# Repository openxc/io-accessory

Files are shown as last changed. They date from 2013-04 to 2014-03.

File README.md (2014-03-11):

OpenXC Dock
===========

This repository is a part of the [OpenXC][] project.

This repository contains the documentation and open source design files for an
example OpenXC accessory that provides a generic I/O interface to add sensors
and actuators to a vehicle. The design was originally released by Ford.

This design has yet to be actually prototyped, so YMMV.

## License

Copyright (c) 2014 Ford Motor Company

The electrical and mechanical designs in this repository are available under the
[Creative Commons Attribution 4.0
International](http://creativecommons.org/licenses/by/4.0/deed.en_US) license.

[OpenXC]: http://openxcplatform.com

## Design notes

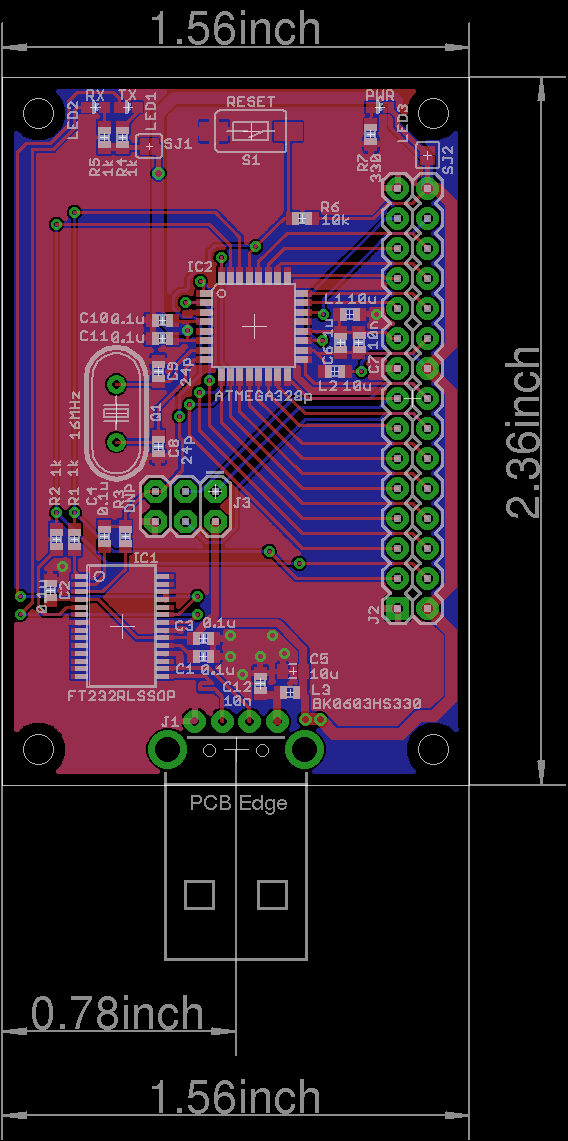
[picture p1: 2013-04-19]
schematics/IO_iJoey.brd.png

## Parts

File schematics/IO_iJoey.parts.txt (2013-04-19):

Partlist

Exported from IO_iJoey.sch at 11/19/12 4:03 PM

EAGLE Version 6.1.0 Copyright (c) 1988-2012 CadSoft

Assembly variant: 

Part     Value          Device                        Package               Library                    Sheet

C1       0.1u           CAP0603-CAP                   0603-CAP              BUG                        1
C2       0.1u           CAP0603-CAP                   0603-CAP              BUG                        1
C3       0.1u           CAP0603-CAP                   0603-CAP              BUG                        1
C4       0.1u           CAP0603-CAP                   0603-CAP              BUG                        1
C5       10u            CAP0805                       0805                  BUG                        1
C6       1u             CAP0603-CAP                   0603-CAP              BUG                        1
C7       10n            CAP0603-CAP                   0603-CAP              BUG                        1
C8       24p            CAP0603-CAP                   0603-CAP              BUG                        1
C9       24p            CAP0603-CAP                   0603-CAP              BUG                        1
C10      0.1u           CAP0603-CAP                   0603-CAP              BUG                        1
C11      0.1u           CAP0603-CAP                   0603-CAP              BUG                        1
C12      10n            CAP0603-CAP                   0603-CAP              BUG                        1
IC1      FT232RLSSOP    FT232RLSSOP                   SSOP28DB              SparkFun-DigitalIC         1
IC2      ATMEGA328p     MEGA8-AI                      TQFP32-08             atmel                      1
J1       USB-A-H        USB-A-H                       USB-A-H               SparkFun-Connectors        1
J2       M15X2          M15X2                         2X15                  BUG                        1
J3                      AVR_SPI_PRG_6PTH              2X3                   SparkFun-Connectors        1
L1       10u            INDUCTOR0603                  0603                  BUG                        1
L2       10u            INDUCTOR0603                  0603                  BUG                        1
L3       BK0603HS330    INDUCTOR0603                  0603                  BUG                        1
LED1     TX             LED0603                       LED-0603              BUG                        1
LED2     RX             LED0603                       LED-0603              BUG                        1
LED3     PWR            LED0603                       LED-0603              BUG                        1
Q1       16MHz          CRYSTAL-GP                    HC49_GP               BUG                        1
R1       1k             RESISTOR0603-RES              0603-RES              BUG                        1
R2       1k             RESISTOR0603-RES              0603-RES              BUG                        1
R3       DNP            RESISTOR0603-RES              0603-RES              BUG                        1
R4       1k             RESISTOR0603-RES              0603-RES              BUG                        1
R5       1k             RESISTOR0603-RES              0603-RES              BUG                        1
R6       10k            RESISTOR0603-RES              0603-RES              BUG                        1
R7       330            RESISTOR0603-RES              0603-RES              BUG                        1
S1       RESET          SWITCH-MOMENTARY-2-SMD-1101NE TACTILE-SWITCH-1101NE SparkFun-Electromechanical 1

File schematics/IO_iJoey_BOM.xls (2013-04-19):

Part | Value | Package | Placement important | Manu | Part # | Volt/Precision | Other | Link | Cost/1k | Notes
C1 | 0.1u | 0603-CAP |  | Kemet | C0603C104K4RACTU | X7R | 16V | http://ca.mouser.com/ProductDetail/Kemet/C0603C104K4RACTU/ | 0.005
C2 | 0.1u | 0603-CAP |  | Kemet | C0603C104K4RACTU | X7R | 16V | http://ca.mouser.com/ProductDetail/Kemet/C0603C104K4RACTU/ | 0.005
C3 | 0.1u | 0603-CAP |  | Kemet | C0603C104K4RACTU | X7R | 16V | http://ca.mouser.com/ProductDetail/Kemet/C0603C104K4RACTU/ | 0.005
C4 | 0.1u | 0603-CAP |  | Kemet | C0603C104K4RACTU | X7R | 16V | http://ca.mouser.com/ProductDetail/Kemet/C0603C104K4RACTU/ | 0.005
C5 | 10u | 0805 |  | Kemet | C0805C106K4PACTU | X5R | 16V | http://ca.mouser.com/ProductDetail/Kemet/C0805C106K4PACTU/ | 0.071
C6 | 1u | 0603-CAP |  | Yageo | CC0603KRX5R8BB105 | X5R | 25V | http://ca.mouser.com/ProductDetail/Yageo/CC0603KRX5R8BB105/ | 0.012
C7 | 10n | 0603-CAP |  | Kemet | C0603C103M5RAC3121 | X7R | 50V | http://ca.mouser.com/ProductDetail/Kemet/C0603C103M5RAC3121/ | 0.032
C8 | 24p | 0603-CAP |  | Murata | GRM1885C1H240GA01D | C0G | 50V | http://ca.mouser.com/ProductDetail/Murata/GRM1885C1H240GA01D/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 | 0.021
C9 | 24p | 0603-CAP |  | Murata | GRM1885C1H240GA01D | C0G | 50V | http://ca.mouser.com/ProductDetail/Murata/GRM1885C1H240GA01D/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 | 0.021
C10 | 0.1u | 0603-CAP |  | Kemet | C0603C104K4RACTU | X7R | 16V | http://ca.mouser.com/ProductDetail/Kemet/C0603C104K4RACTU/ | 0.005
C11 | 0.1u | 0603-CAP |  | Kemet | C0603C104K4RACTU | X7R | 16V | http://ca.mouser.com/ProductDetail/Kemet/C0603C104K4RACTU/ | 0.005
C12 | 10n | 0603-CAP |  | Kemet | C0603C103M5RAC3121 | X7R | 50V | http://ca.mouser.com/ProductDetail/Kemet/C0603C103M5RAC3121/ | 0.032
IC1 | FT232RLSSOP | SSOP28DB |  | FTDI | FT232RL-REEL | 5.25V |  | http://ca.mouser.com/ProductDetail/FTDI/FT232RL-REEL/ | 2.84
IC2 | ATMEGA328p | TQFP32-08 |  | Atmel | ATMEGA328P-AU | 5.5V |  | http://ca.mouser.com/ProductDetail/Atmel/ATMEGA328P-AU/ | 1.85 | Any ATMEGA328P
J1 | USB-A-H | USB-A-H | YES | Samtec | USB-AM-S-F-B-TH | 1A |  | http://components.arrow.com/part/detail/43114295S7160411N1004?region=na | 0.8266 | Any USB-AM-S will do, sparkfun part # PRT-00437 also valid
J2 | M15X2 | 2X15 | YES | Samtec | SSW-130-02-X-D-RA |  |  | http://www.newark.com/jsp/search/productdetail.jsp?SKU=83P0035&CMP=AFC-OPH | 3.11 | The X in the part number can be any value, finish is unimportant
J3 | AVR_SPI_PRG_6PTH | 2X3 | YES |  | DNP |  |  | http://www.te.com/catalog/pn/en/826632-3 |  | DO NOT POPULATE, Leave room within enclosure if possible
L1 | 10u | 0603 |  | TDK | MLZ1608N100L | 20.00% | 300mA | http://ca.mouser.com/ProductDetail/TDK/MLZ1608N100L/ | 0.059
L2 | 10u | 0603 |  | TDK | MLZ1608N100L | 20.00% | 300mA | http://ca.mouser.com/ProductDetail/TDK/MLZ1608N100L/ | 0.059
L3 |  | 0603 |  | Taiyo Yuden | BKP1608HS330-T | 25.00% | 3A | http://ca.mouser.com/ProductDetail/Taiyo-Yuden/BKP1608HS330-T/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 | 0.042
LED1 | TX | LED-0603 | YES | Lumex | SML-LX0603SYW-TR | 2.0v | 30mA | http://ca.mouser.com/ProductDetail/Lumex/SML-LX0603SYW-TR/?qs=sGAEpiMZZMtEjy7lsqBi5RJSiXBATNyvg4Bl9BQ6i1I%3d | 0.31 | Yellow
LED2 | RX | LED-0603 | YES | Lumex | SML-LX0603SUGW-TR | 2.2v | 25mA | http://ca.mouser.com/ProductDetail/Lumex/SML-LX0603SUGW-TR/?qs=sGAEpiMZZMtEjy7lsqBi5RJSiXBATNyvW8f9Im9YZTw%3d | 0.353 | Green
LED3 | PWR | LED-0603 | YES | Lumex | SML-LX0603SRW-TR | 1.7V | 30mA | http://ca.mouser.com/ProductDetail/Lumex/SML-LX0603SRW-TR/?qs=sGAEpiMZZMtEjy7lsqBi5RJSiXBATNyvPQrK1QY4BhE%3d | 0.1 | Red
Q1 | 16MHz | HC49_GP | YES | TXC | 9B-16.000MAAJ-B | 30PPM | 18pF | http://ca.mouser.com/ProductDetail/TXC-Corporation/9B-16000MAAJ-B/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 | 0.193
R1 | 1k | 0603-RES |  | KOA Speer | RK73B1JTTD102J | 5.00% | 100mW | http://ca.mouser.com/ProductDetail/KOA-Speer/RK73B1JTTD102J/ | 0.018
R2 | 1k | 0603-RES |  | KOA Speer | RK73B1JTTD102J | 5.00% | 100mW | http://ca.mouser.com/ProductDetail/KOA-Speer/RK73B1JTTD102J/ | 0.018
R3 | DNP | 0603-RES |  |  | DNP |  |  | http://ca.mouser.com/ProductDetail/KOA-Speer/RK73B1JTTD102J/ |  | DO NOT POPULATE, optional chip reset source
R4 | 1k | 0603-RES |  | KOA Speer | RK73B1JTTD102J | 5.00% | 100mW | http://ca.mouser.com/ProductDetail/KOA-Speer/RK73B1JTTD102J/ | 0.018
R5 | 1k | 0603-RES |  | KOA Speer | RK73B1JTTD102J | 5.00% | 100mW | http://ca.mouser.com/ProductDetail/KOA-Speer/RK73B1JTTD102J/ | 0.018
R6 | 10k | 0603-RES |  | KOA Speer | RK73B1JTTD103J | 5.00% | 100mW | http://ca.mouser.com/ProductDetail/KOA-Speer/RK73B1JTTD103J/?qs=sGAEpiMZZMvdGkrng054t1eDf6HruEFgjWOR00sSOC4%3d | 0.018
R7 | 330 | 0603-RES |  | KOA Speer | RK73B1JTTD331J | 5.00% | 100mW | http://ca.mouser.com/ProductDetail/KOA-Speer/RK73B1JTTD331J/?qs=sGAEpiMZZMvdGkrng054tzXZVdtYgUO272r6ardb0NA%3d | 0.018
S1 | RESET | TACTILE-SWITCH-1101NE | YES | C&K | RS-032G05A3-SM RT | 12V | 50mA | http://www.digikey.com/product-detail/en/RS-032G05A3-SM%20RT/CKN10388CT-ND/2747197 | 0.352

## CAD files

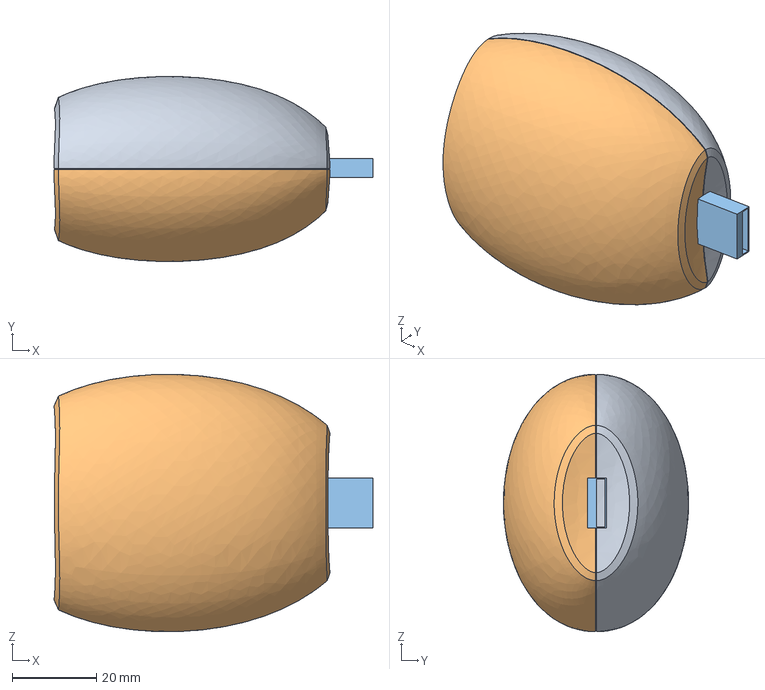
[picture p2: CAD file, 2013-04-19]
schematics/ijoey_assy_v4.stp
75.8 x 44.0 x 61.2 mm
IJOEY_BODY_V4
24_8_USB_CONNECTOR

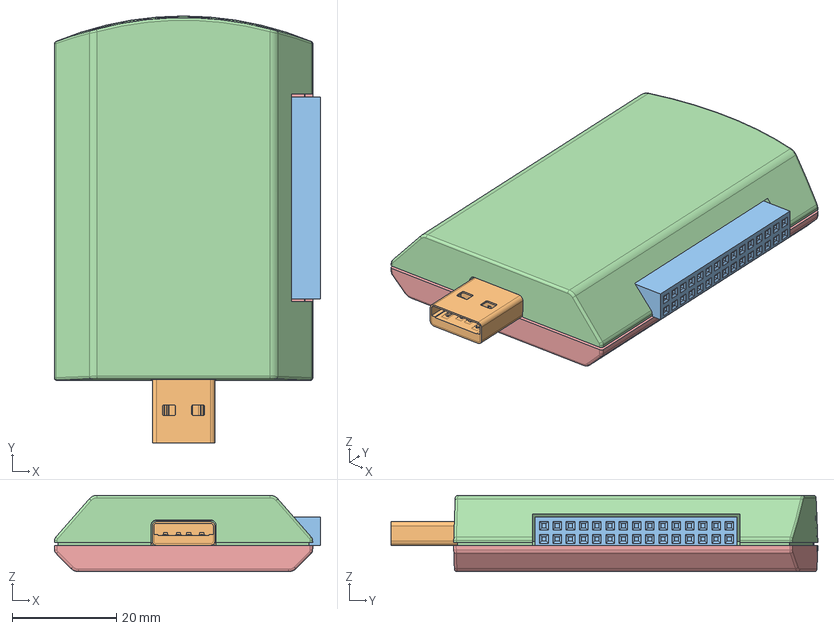
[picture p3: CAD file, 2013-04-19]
enclosure/ijoey_revX01_120312b.stp
51.1 x 81.9 x 14.7 mm
IJOEY_PCB
USB-AM-S-X-X-TH
SSW-130-02-X-T-RA-076
IJOEY_TOP
IJOEY_BOTT
M2_5MM_SCREW-BF x 4

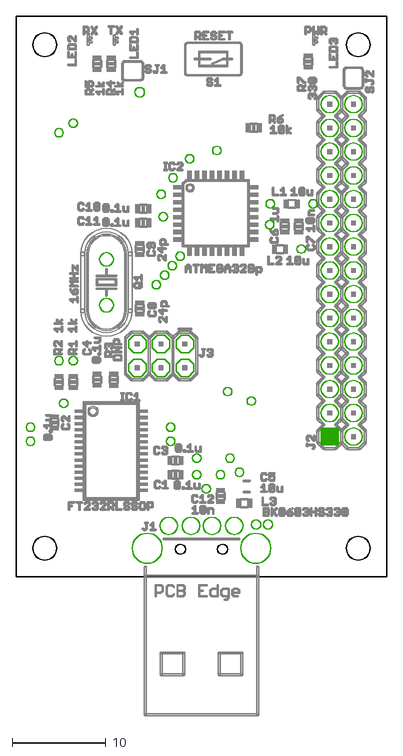
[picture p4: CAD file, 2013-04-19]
schematics/IO_iJoey.dxf
39.6 x 74.8

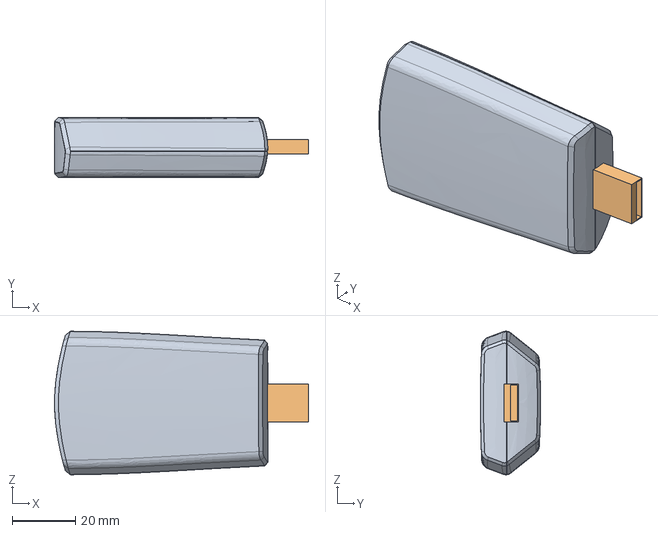
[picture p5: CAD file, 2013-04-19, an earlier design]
schematics/ijoey_assy_v1.stp
80.1 x 19.0 x 45.3 mm
IJOEY_BODY_V1
24_8_USB_CONNECTOR

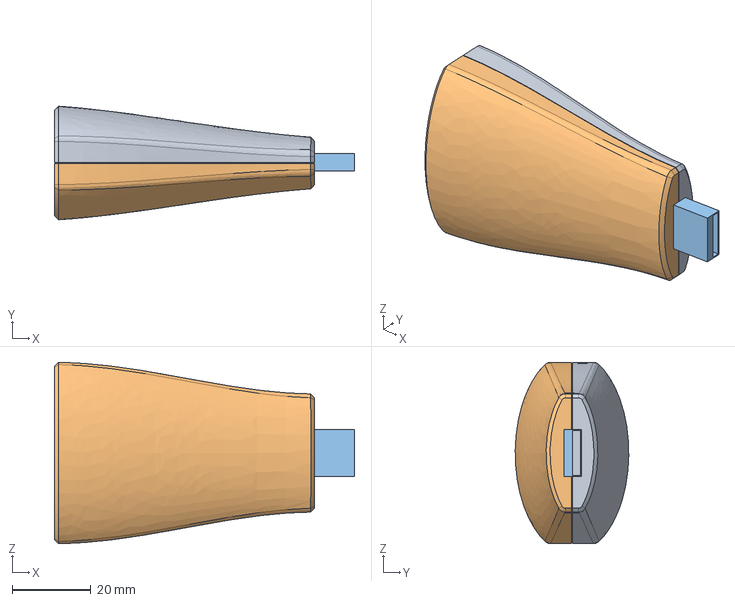
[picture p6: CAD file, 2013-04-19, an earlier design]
schematics/ijoey_assy_v2.stp
76.2 x 28.8 x 46.0 mm
IJOEY_BODY_V2
24_8_USB_CONNECTOR

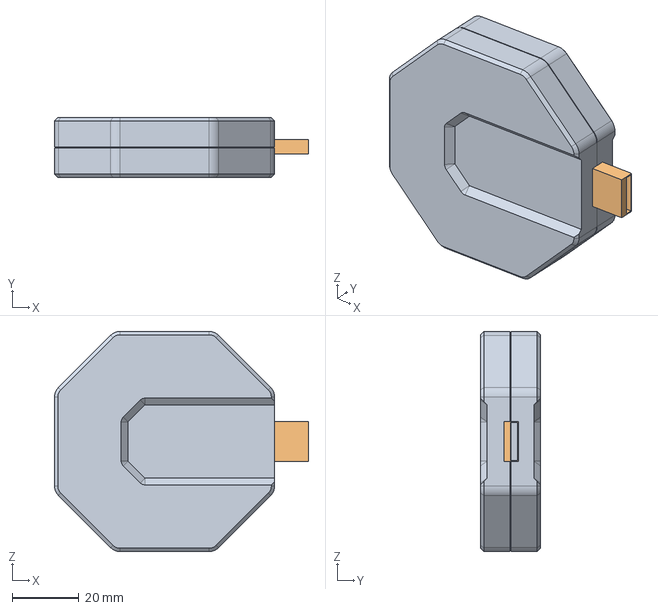
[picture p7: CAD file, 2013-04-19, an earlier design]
schematics/ijoey_assy_v3.stp
76.2 x 18.0 x 66.0 mm
IJOEY_BODY_V3
24_8_USB_CONNECTOR

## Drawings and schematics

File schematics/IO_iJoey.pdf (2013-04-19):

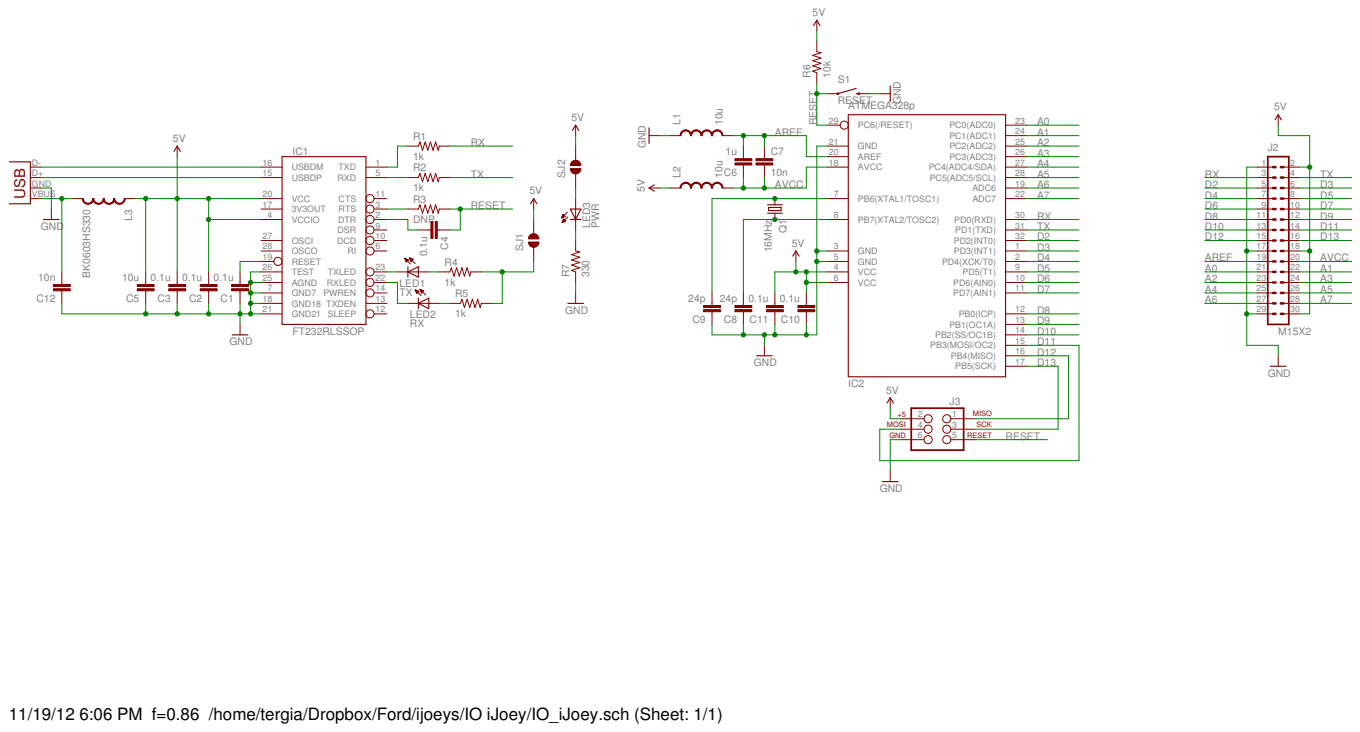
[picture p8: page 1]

11/19/12 6:06 PM f=0.86 /home/tergia/Dropbox/Ford/ijoeys/IO iJoey/IO_iJoey.sch (Sheet: 1/1)

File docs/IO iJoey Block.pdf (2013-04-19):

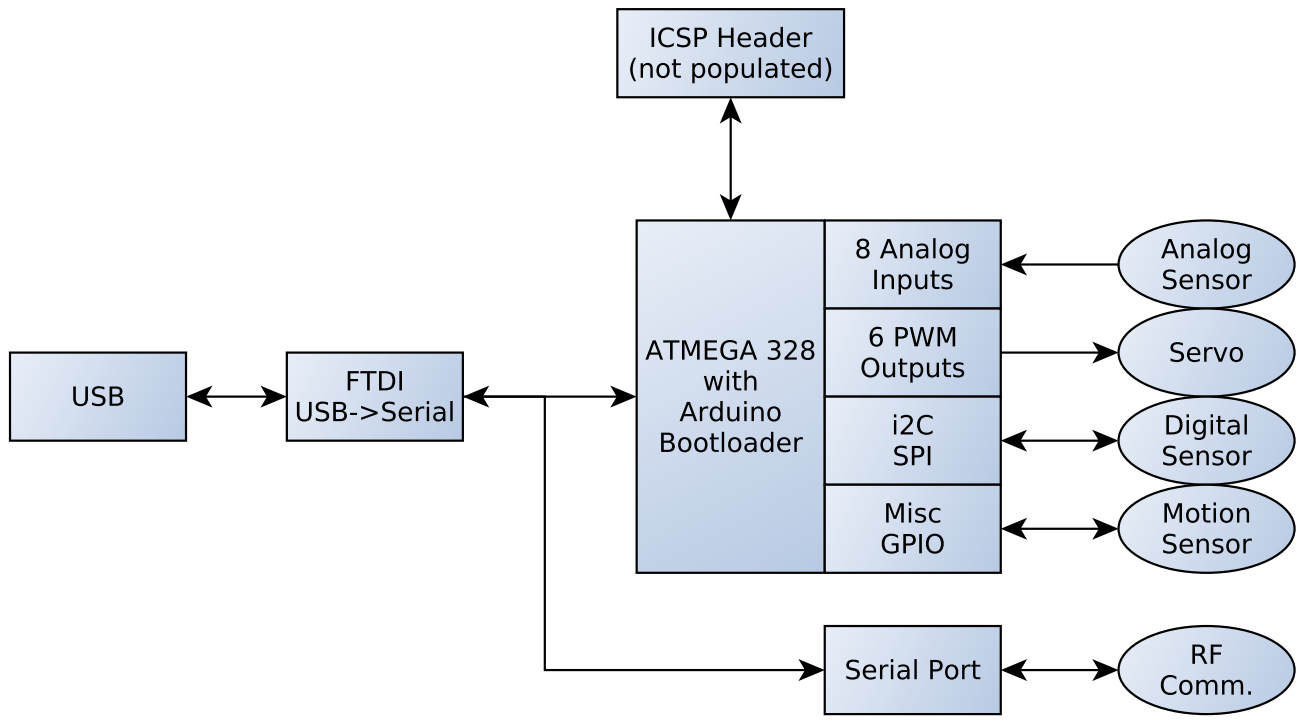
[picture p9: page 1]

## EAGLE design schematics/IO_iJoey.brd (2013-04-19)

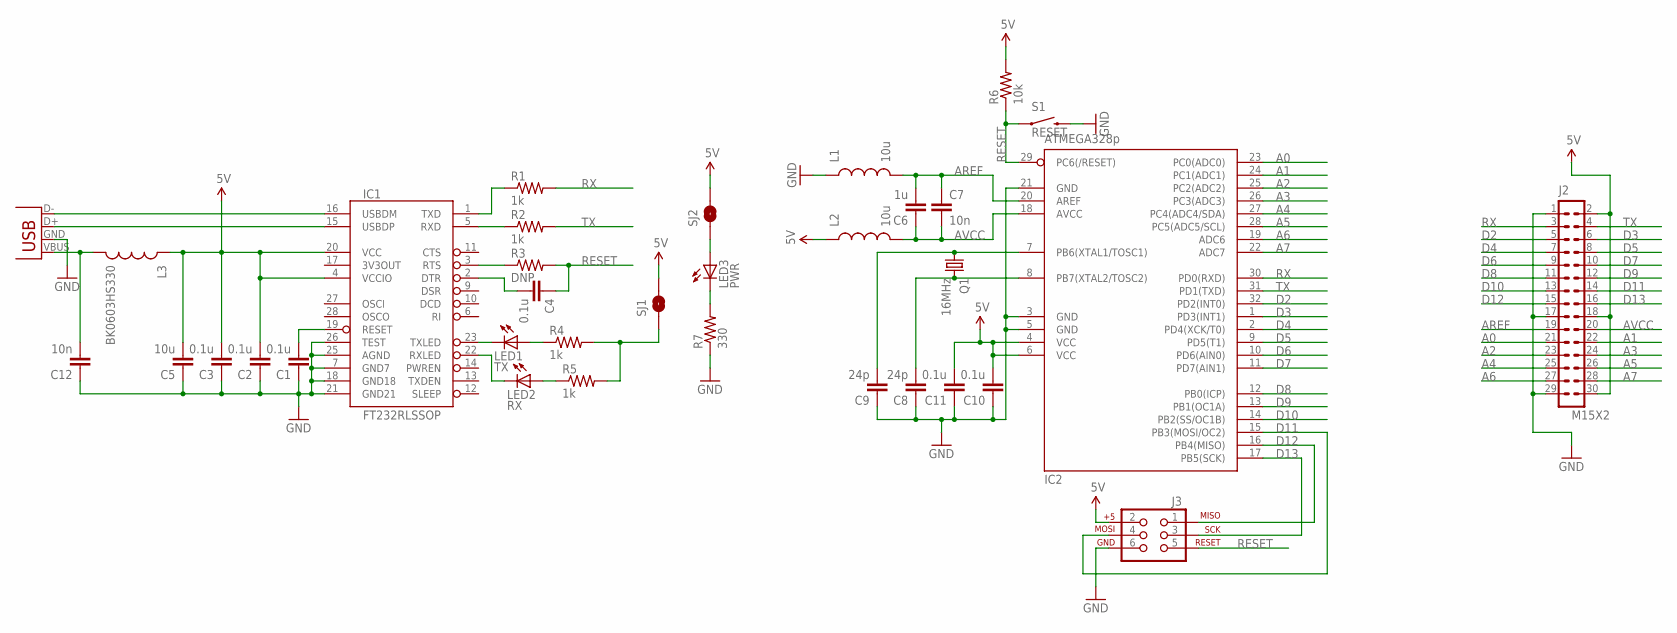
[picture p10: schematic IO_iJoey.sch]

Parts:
C1, C2, C3, C4, C10, C11: 0.1u; 0603-CAP
C5: 10u; 0805
C6: 1u; 0603-CAP
C7, C12: 10n; 0603-CAP
C8, C9: 24p; 0603-CAP
IC1: FT232RLSSOP; SSOP28DB
IC2: ATMEGA328p; TQFP32-08
J1: USB-A-H
J2: M15X2; 2X15
J3: AVR_SPI_PRG_6PTH; 2X3
L1, L2: 10u; 0603
L3: BK0603HS330; 0603
LED1: TX; LED-0603
LED2: RX; LED-0603
LED3: PWR; LED-0603
Q1: 16MHz; HC49_GP
R1, R2, R4, R5: 1k; 0603-RES
R3: DNP; 0603-RES
R6: 10k; 0603-RES
R7: 330; 0603-RES
S1: RESET; TACTILE-SWITCH-1101NE
SJ1, SJ2: SOLDERJUMPERNC; SJ_2S

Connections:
5V: C2.2, C3.2, C5.2, C10.2, C11.2, IC1.4 (VCCIO), IC1.20 (VCC), IC2.4 (VCC), IC2.6 (VCC), J2.2, J2.18, J2.30, J3.2, L2.1, L3.1, R6.2, SJ1.2, SJ2.2
A0: IC2.23 (PC0(ADC0)), J2.21
A1: IC2.24 (PC1(ADC1)), J2.22
A2: IC2.25 (PC2(ADC2)), J2.23
A3: IC2.26 (PC3(ADC3)), J2.24
A4: IC2.27 (PC4(ADC4/SDA)), J2.25
A5: IC2.28 (PC5(ADC5/SCL)), J2.26
A6: IC2.19 (ADC6), J2.27
A7: IC2.22 (ADC7), J2.28
AREF: C6.2, C7.1, IC2.20 (AREF), J2.19, L1.2
AVCC: C6.1, C7.2, IC2.18 (AVCC), J2.20, L2.2
D2: IC2.32 (PD2(INT0)), J2.5
D3: IC2.1 (PD3(INT1)), J2.6
D4: IC2.2 (PD4(XCK/T0)), J2.7
D5: IC2.9 (PD5(T1)), J2.8
D6: IC2.10 (PD6(AIN0)), J2.9
D7: IC2.11 (PD7(AIN1)), J2.10
D8: IC2.12 (PB0(ICP)), J2.11
D9: IC2.13 (PB1(OC1A)), J2.12
D10: IC2.14 (PB2(SS/OC1B)), J2.13
D11: IC2.15 (PB3(MOSI/OC2)), J2.14, J3.4
D12: IC2.16 (PB4(MISO)), J2.15, J3.1
D13: IC2.17 (PB5(SCK)), J2.16, J3.3
GND: C1.1, C2.1, C3.1, C5.1, C8.1, C9.1, C10.1, C11.1, C12.1, IC1.7 (GND7), IC1.18 (GND18), IC1.21 (GND21), IC1.25 (AGND), IC1.26 (TEST), IC2.3 (GND), IC2.5 (GND), IC2.21 (GND), J1.GND (VBUS), J2.1, J2.17, J2.29, J3.6, L1.1, R7.1, S1.P$2 (2)
unnamed: IC1.15 (USBDP), J1.D+ (D-)
unnamed: IC1.16 (USBDM), J1.D- (D+)
unnamed: C4.2, IC1.2 (DTR)
unnamed: C1.2, IC1.19 (RESET)
unnamed: C12.2, J1.VBUS (GND), L3.2
unnamed: IC1.3 (RTS), R3.1
unnamed: IC1.5 (RXD), R2.1
unnamed: IC1.1 (TXD), R1.1
unnamed: LED3.C, R7.2
unnamed: IC1.23 (TXLED), LED1.C
unnamed: IC1.22 (RXLED), LED2.C
unnamed: LED2.A, R5.1
unnamed: LED1.A, R4.1
unnamed: R4.2, R5.2, SJ1.1
unnamed: LED3.A, SJ2.1
unnamed: C9.2, IC2.7 (PB6(XTAL1/TOSC1)), Q1.1
unnamed: C8.2, IC2.8 (PB7(XTAL2/TOSC2)), Q1.2
RESET: C4.1, IC2.29 (PC6(/RESET)), J3.5, R3.2, R6.1, S1.P$1 (1)
RX: IC2.30 (PD0(RXD)), J2.3, R1.2
TX: IC2.31 (PD1(TXD)), J2.4, R2.2

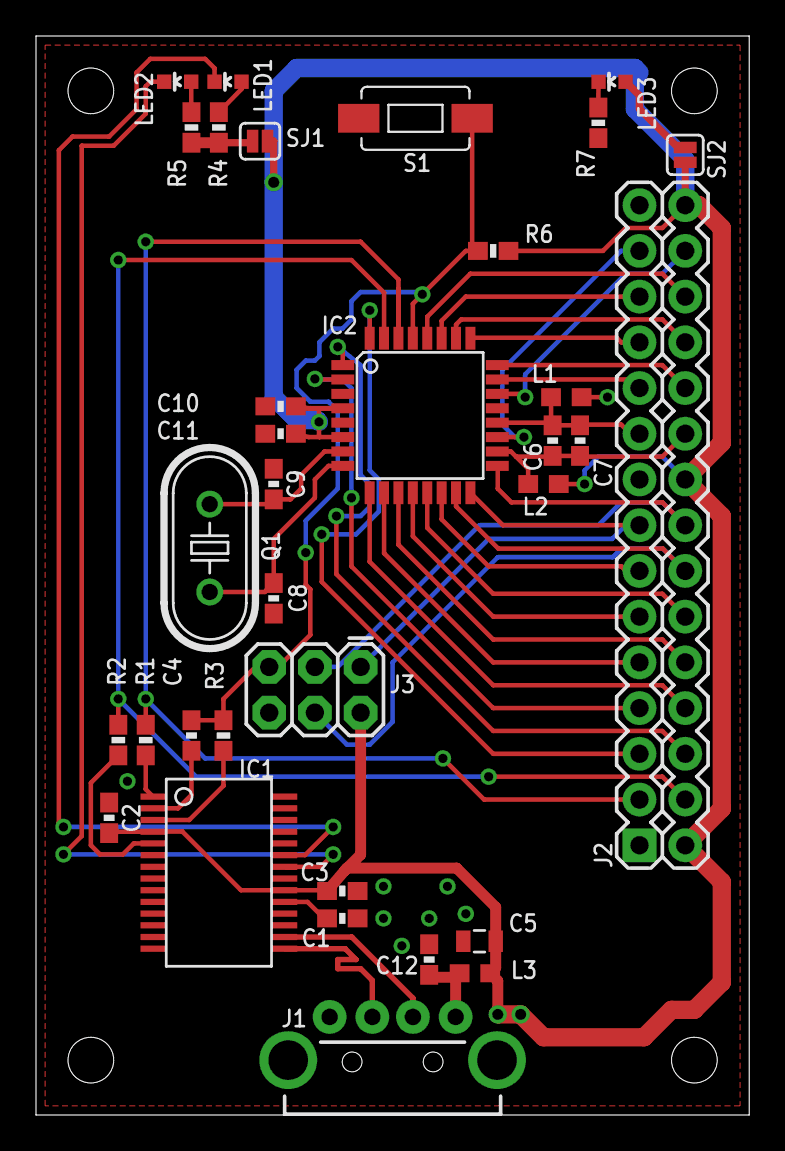
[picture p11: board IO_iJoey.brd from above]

Board: 2 copper layers, 39.6 x 59.9 mm, 34 parts (0 on the bottom side), 44 nets.

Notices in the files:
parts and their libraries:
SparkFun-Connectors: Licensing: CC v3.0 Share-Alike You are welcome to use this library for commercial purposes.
